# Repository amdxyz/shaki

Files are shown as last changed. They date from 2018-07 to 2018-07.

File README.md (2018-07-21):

# AMDX Shaki

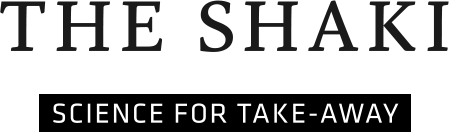
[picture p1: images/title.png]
Shaki title picture


Push - Shake - Love: that's as simple as how the "Shaki" works. If you push a button and shake the stick, a message, a name or a symbol appears in the air. But what the Shaki actually demonstrates is a highly complex phenomenon - the Persistence of vision.

## POV

POV stands for Persistence of vision (https://en.wikipedia.org/wiki/Persistence_of_vision)
The image of an object stays on the retina even after stopping looking at it as the eye and brain actually retain a visual impression for about 1/20 th of a second. It is the principle of movies and animations - and of the small exhibit we at Archimedes Exhibitions created to make this scientific phenomenon playfully comprehensive. You can put the Shaki in your trouser pocket and experience and learn about the Persistence of vision wherever you like, alone or in groups.

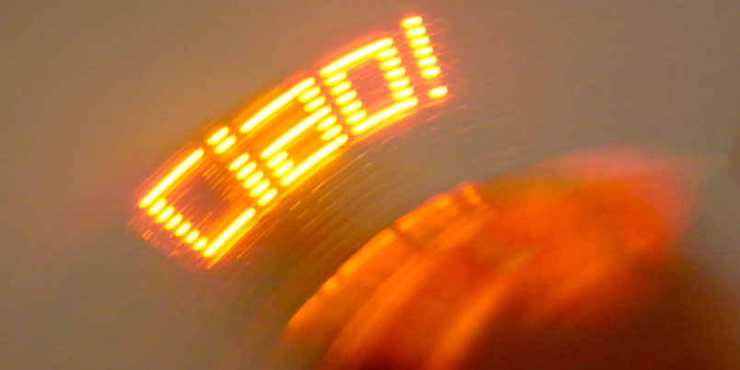
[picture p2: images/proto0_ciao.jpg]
POV Sample picture


## History

The Shaki was developed as part of an internal competition we regularly launch at Archimedes Exhibitions to cultivate creativity and innovative ideas outside the daily working routine. The goal of the competition was to produce a cheap and insightful giveaway for the upcoming ECSITE annual conference (https://www.ecsite.eu/).

The background idea behind our Shaki was kind of a „Gadgetification": taking one of our original size exhibits and shrinking it until it fits into a trouser pocket.

The Shaki is the gadgetified version of our "Spinning Display", a rotating POV display developed for the Science and Technology Centre Ostrava (CZ), as part of the "World of Nature" exhibition (http://stcostrava.cz/setrvacnost-oka).

Archimedes Exhibitions gave away 200 Shakis units among the participants of the 2018 ECSITE conference and, after its big success, decided to release the Shaki's firmware, tools and PCB as open source.

Shaki prototypes

## Components and operation

The Shaki hardware has five main components:

* battery: its power source
* button: connects the battery to the rest of the components
* microcontroller: the brain
* accelerometer: the sensor that detects a shake
* LEDs bar: 8 small light emitting diodes that paint the stored pictures in the air

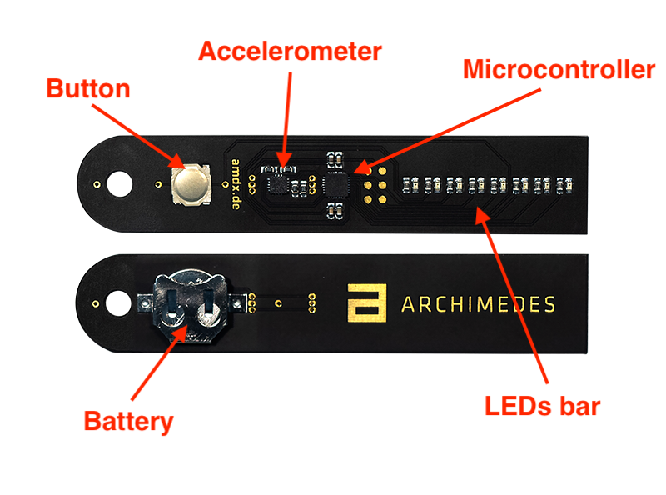
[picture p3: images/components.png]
Components


### Theory of operation

Once the button is pressed and as long as it's being kept pressed, the microcontroller talks to the accelerometer and attempts to detect the motion of the stick in real time. The accelerometer reports its readouts 1.600 times per second.

The idea is to detect the two extremes of a shake motion (a rapid side to side oscillation) and to paint a frame while moving from left to right.

As soon as the microcontroller decides that the stick is moving from left to right, it starts to stream the current frame to the LEDs bar. The frame is composed of several columns and each column is extracted and "transferred" to the LEDs bar using a timer. This transfer means that some LEDs will be lit, some not, according to the "white" or "black" pixels set in the frame.

Each 2.4ms a new column is moved from the microcontroller's memory to the LEDs bar until all the columns have been transferred. From this point on the LEDs shut down and the microcontroller waits until the rightmost point is reached.

Once the rightmost point is reached, the microcontroller decides whether to advance to the next frame or to paint the last one again (depending on the amount of shakes-per-frame defined). The LEDs are kept off until the cycle repeats.

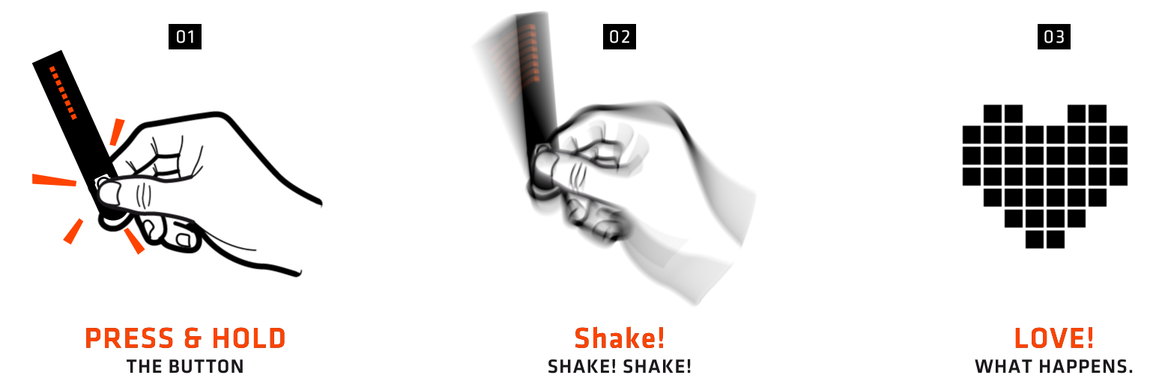
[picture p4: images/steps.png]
Steps


### More details on the components

* Microcontroller: ATMEL ATTiny88 (8kB FLASH, 512B SRAM) clocked at 8Mhz via its internal RC oscillator
* Accelerometer: ST LIS3DH MEMS accelerometer (16bit, I2C/SPI, 5300Hz max update rate)

The accelerometer is connected to the microcontroller via its I2C interface.

## What to find in the repository

This repository is composed of the following:

* eagle: EagleCAD schematics, PCB layout and BOM
* firmware: the software that runs inside the Shakis
* tools: converter and authoring tools to customise the displayed frames

Each folder contains a detailed readme file.

## FAQ

AKA frequently asked questions:

### Can I get an assembled, ready-to-use Shaki?

Yes, write to us: shaki {a} amdx.de

### Can I produce, customise, sell the Shaki?

As long as it fits the terms of the [LICENSE](https://github.com/amdxyz/shaki/blob/master/LICENSE.md), you're more than welcome.

### How can I customise my Shaki?

This repository provides everything you need to do any customisation you may have in mind, but the process requires some technical skills and tools.

In short:

* Produce the frames using a graphic authoring tool or the included of_bitpuncher tool
* Convert the authored graphic (not required when using of_bitpuncher)
* Compile the firmware
* Upload the firmware to the Shaki using a programmer and a programming jig

### Why no USB?

One of the Shaki's primary requirements was to minimize its production costs. It wasn't initially supposed to be released to the public, so we didn't consider a consumer-grade programming interface.

### How can I contribute?

Feel free to file an issue or post a push request!

### Any media?

You can watch a short presentation here: https://www.youtube.com/watch?v=L5a6pu70XJo

And a brief introduction here: http://www.amdx.de/shaki

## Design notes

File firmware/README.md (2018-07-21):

# Shaki firmware

This directory contains the firmware for the Shaki board.

Building the firmware is a required step for customizing the stored frames, since they're backed into the firmware itself (and residing in flash).

The firmware can be built using two IDEs:

* Platformio (http://www.platformio.org)
* Atmel Studio 7 (https://www.microchip.com/mplab/avr-support/atmel-studio-7)

## Frame data

The simplest way to hack the Shaki is to alter the content of its frame buffer.

All the frames shown during a shake, are stored into the header frame_data.h in the variable named "frames".

The file can be generated using one of the two tools provided:

* bitmap_converter
* of_bitpuncher

More information is provided inside the tools folder.

## Modifying the source and/or building it

There are three methods that can be followed to build the firmware:

### Using platformio command line tools

Build the firmware by issuing:

	$ pio run

The firmware can be then uploaded using the target "upload":

	$ pio run -t upload

Check below for notes about uploading.

### Using platformio IDE

Open the project in the IDE and press either build or upload.

### Using Atmel Studio 7

Navigate into atmelstudio and double-click the solution file "atmelstudio.atsln".

The solution can be built pressing F7 (or choosing "Build solution" from the build menu).

In order to upload the firmware or run a debug session, a programming tool must be defined.

## Uploading the firmware

In order to upload the firmware, you need the following tools:

* AVRISP-MKII or compatible
* ISP pogo-pins jig (eg: Sparkfun KIT-11591 https://www.sparkfun.com/products/11591)

The jig should be applied over the exposed programming pads as shown in the following picture:

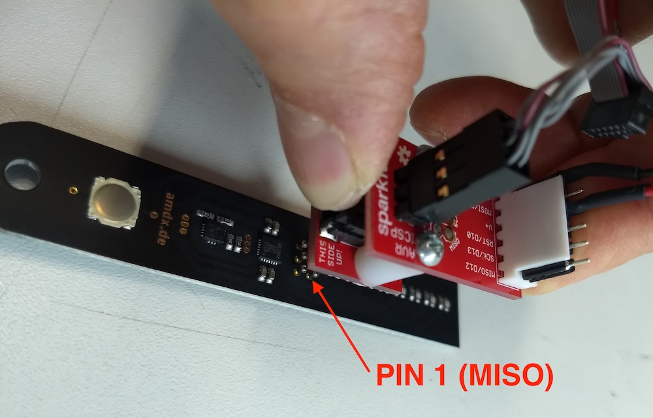
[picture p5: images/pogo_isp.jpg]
Pogo-pins ISP


Once the pogo pins are properly in contact with the pads, the programming can be carried on.

### Using Atmel-ICE

As the AVRISP is no longer in production, it can be replaced with the newer atmel-ICE.

In order to use it with platformio, edit the file boards/shaki.json and modify the key "protocol" under "upload":

	"protocol": "avrispmkii",

to

	"protocol": "atmelice_isp",

Make sure the programmer pigtail is connected to the "AVR" port.

## Fuses

The AMDX Shaki board comes provisioned and pre-programmed with a default pattern. In case you produced the board by yourself, the microcontroller must be provisioned with fuses setting.

The fuses hexes are:

* High: 0xd7
* Low: 0xee

The directory "provisioning" contains two scripts that can be used to set the fuses using avrdude and an AVRISP-MKII programmer. They can be used under windows (.bat) and linux, OSX (.sh), provided that avrdude is available in the PATH.

## Debugging

### Test pattern

A test pattern can be activated by adding a define TEST_PATTERN (see firmware/platfomio.ini).

Once flashed, the firmware will provide two brief blinks to signal the detection of the two motion extremes (left and right).

### Timing test point TP1

TP1 is a timing pin that can be connected to an oscilloscope in order to perform motion analysis.

It offers two debugging modes:

* DEBUG_ON_COLUMN : every time a new column from a frame is transferred to the LED bar, this line asserts shortly
* DEBUG_ON_SHAKE : the line asserts during a left-to-right motion and deasserted otherwise

The two modes can be activated by defining the respective identifiers. Check firmware/platformio.ini file for more information.

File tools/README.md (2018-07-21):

# Tools

This directory contains tools designed to ease the customization of the Shaki's default painted frames.

## Bitmap converter

A python console tool to convert a set of bitmap images into the final target format (a C-Header file), that can be compiled along with the firmware.

## of_bitpuncher

A fully fledged application that allows to design a pattern / sequence.

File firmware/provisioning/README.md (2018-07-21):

# Fuses provisioning

Shaki boards produced by AMDX come always provisioned and require no additional setup.

Self-produced boards require one-time setup for the fuses settings.

## Under windows (Atmel Studio 7)

Make sure the programmer is connected via USB to your PC

* Open the solution file (optional)
* Open the device programming tool (Tools -> Device Programming)
* Select the programmer from the Tool dropdown
* If not selected, choose "ATTiny88" as device
* Press "Apply"
* Make sure that the pogo-pins jig is attached to the board
* Press "Read" to check connection and device signature
* Select "Fuses" on the left navigation column
* Uncheck "LOW.CKDIV8"
* Press "Program"

Ensure that the summary of the action reports all entries with a trailing "OK"

## Under windows (avrdude)

**Note: the drivers installed by Atmel Studio are incompatible with avrdude**

Prerequisite: avrdude must be in the path or the exe and the config file must be moved to this directory

* Make sure that the pogo-pins jig is attached to the board
* Execute the bat file

## Under OSX or Linux

Prerequisite: avrdude must be installed (via homebrew for OSX or any packaging system under linux)

* Make sure that the pogo-pins jig is attached to the board
* Execute the shell script

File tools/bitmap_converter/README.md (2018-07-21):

# Bitmap to Shaki frame data header converter

This tool converts a set of bitmap files to the C-header format required by the firmware to store the frames data.

## Requirements

### Converter

The converter requires python 2.7 or python 3 and uses PIL/Pillow for image operations. This requirement can be fulfilled in different ways depending on the working platform.

A typical workflow using virtualenv:

	$ virtualenv _venv
	$ source _venv/bin/activate
	$ pip install -Ur requirements.txt

Remember to activate the virtualenv before using the converter.

### Input files

The converter expects the input files to meet the following requirements:

* Color mode: bitmap (1 bit per pixel)
* White pixels turn the LEDs on
* The height must be exactly 8 pixels
* The width is arbitrary, but widths below 12 work best
* Any common image compression is supported, PNG is suggested
* The number of frames is arbitrary (see below for the memory limits)

Check the files provided in the samples folder.

## Usage

The simplest usage example:

	$ ./convert.py samples/amdx/*

The invocation above uses two sample bitmaps provided in the amdx samples folder and converts them into a file "frame_data.h" in the current working directory.

A more complete example:

	$ ./convert.py --spf 2 --output ../../firmware/src/frame_data.h samples/helloworld/*

* --spf 2: indicates that each frame should be painted for two shakes
* --output ../../firmware/src/frame_data.h: overwrite the current frame_data.h file
* Files list: this is the ordered list of bitmap frames to convert. Globbing is supported.

### Note about spf

The "spf" parameter (standing for shakes-per-frame) defines how the frames are coupled to the POV scan (or shake).

A value greater than zero (the default of the tool is 5) will repeat the paint of a single frame for more than once.

Repeating helps the user to properly understand the painted frame.

An SPF of 1 may be used with frames sequences that are supposed to show a fluid animation and where the sequence in its whole is more representative than each single frame.

## Memory limits

Each row requires one byte of flash memory. The memory available for the frame buffer is around 7200 bytes, which means 7200 columns maximum in total.

When using 8x8 frames, for example, the maximum number of frames that can be stored is roughly 112.

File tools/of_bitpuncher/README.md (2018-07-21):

# of_bitpuncher

This application helps to create patterns and sequences through a graphical interface. It allows you to upload new patterns to your Shaki by using platformIO or to export them to a C-header file suitable for the Shaki firmware.

**Note: Tested on OSX with openframeworks 0.10.0**

## Requirements

### openframeworks

The of_bitpuncher app is based on openframeworks, an open source C++ toolkit. Download it from https://openframeworks.cc/.

The app uses the addon ofxGuiExtended by frauzufall. Clone it to the openframeworks addons directory.

    $ cd ../of_vX.XX.X_osx_release/addons
    $ git clone https://github.com/frauzufall/ofxGuiExtended.git

Create a new openframeworks project on top of the of_bitpuncher source files. Navigate to the project generator app coming along with openframeworks.

    $ open ../of_vX.XX.X_osx_release/projectGenerator/projectGenerator.app

Under the tab 'create/update' fill in the following:

    Project name: 'of_bitpuncher'
    Project path: '../tools/'
    Addons: 'ofxGuiExtended'

Click on 'Generate'. This will automatically create the make file needed to compile the software on your computer.

To compile:

    $ cd ../tools/of_bitpuncher
    $ make

To run the app:

    $ make run
Alternatively execute ../tools/of_bitpuncher/bin/of_bitpuncher.app

### platformIO

PlatformIO is required to compile and upload the produced patterns / sequences to the Shaki with a one-button operation. Alternatively, the patterns / sequences can be exported to a C-header frame data file suitable for the current firmware.

## Usage

### Edit a frame

Create a pattern by clicking / dragging the mouse over the 8x8 matrix on the top. It is also possible to use the key input to have a quick access to predefined letters and numbers. Only letters from 'a' to 'z' and numbers from '0' to '9' are implemented.

### Create a sequence

In order to create words, animation or multiple icons create a sequence by adding more frames. Click on '+' to add one frame or click on the trash can icon to delete the currently selected frame.

### Shakes per frame

'Shakes per frame' defines the number of shakes before the Shaki advances to the next frame.

### Templates

Pick one of the templates on the right-hand side for quick and easy start. There is also the option to add the current sequence to the template list by clicking on 'Add template' at the bottom right.

### Reset / Upload / Export

Click on 'Reset' to start from scratch. 'Upload' will flash the firmware on the Shaki (platformIO required). 'Export' allows you to save the frame_data.h file on you computer.

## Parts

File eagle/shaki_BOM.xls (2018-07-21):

Part Name | Quantity | Type | Package | Value | Company | Part Number
R1-R4 | 4 | Resistor | 0603 | 10k
R10-R17 | 8 | Resistor | 0603 | 100R/1%
C1,C3 | 2 | Capacitor | 0603 | 100nF
C2 | 1 | Capacitor | 0603 | 1µF/16V
C4 | 1 | Capacitor | 0603 | 10µF/16V
D1-D8 | 8 | LED Orange | 0603 |  | Lite-On-Inc. | LTST-C194KFKT
U1 | 1 | Microcontroller | QFN28 |  | Microchip | ATTINY88-MMU
U2 | 1 | 3 Axis Sensor | LGA16 3x3 |  | ST | LIS3DHTR
Bat1 | 1 | 1220 Battery Holder | 1220 SMD | 3V | Keystone | 3000
SW1 | 1 | SMD Button |  |  | Alps | SKRRABE010

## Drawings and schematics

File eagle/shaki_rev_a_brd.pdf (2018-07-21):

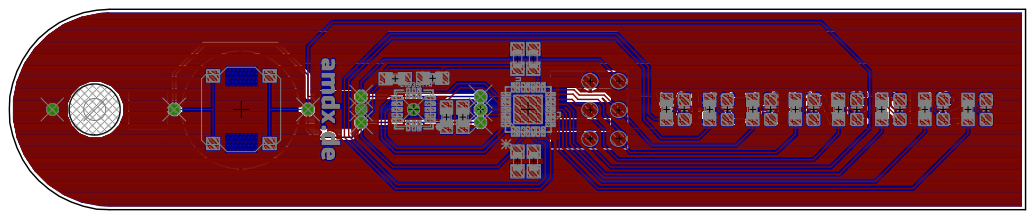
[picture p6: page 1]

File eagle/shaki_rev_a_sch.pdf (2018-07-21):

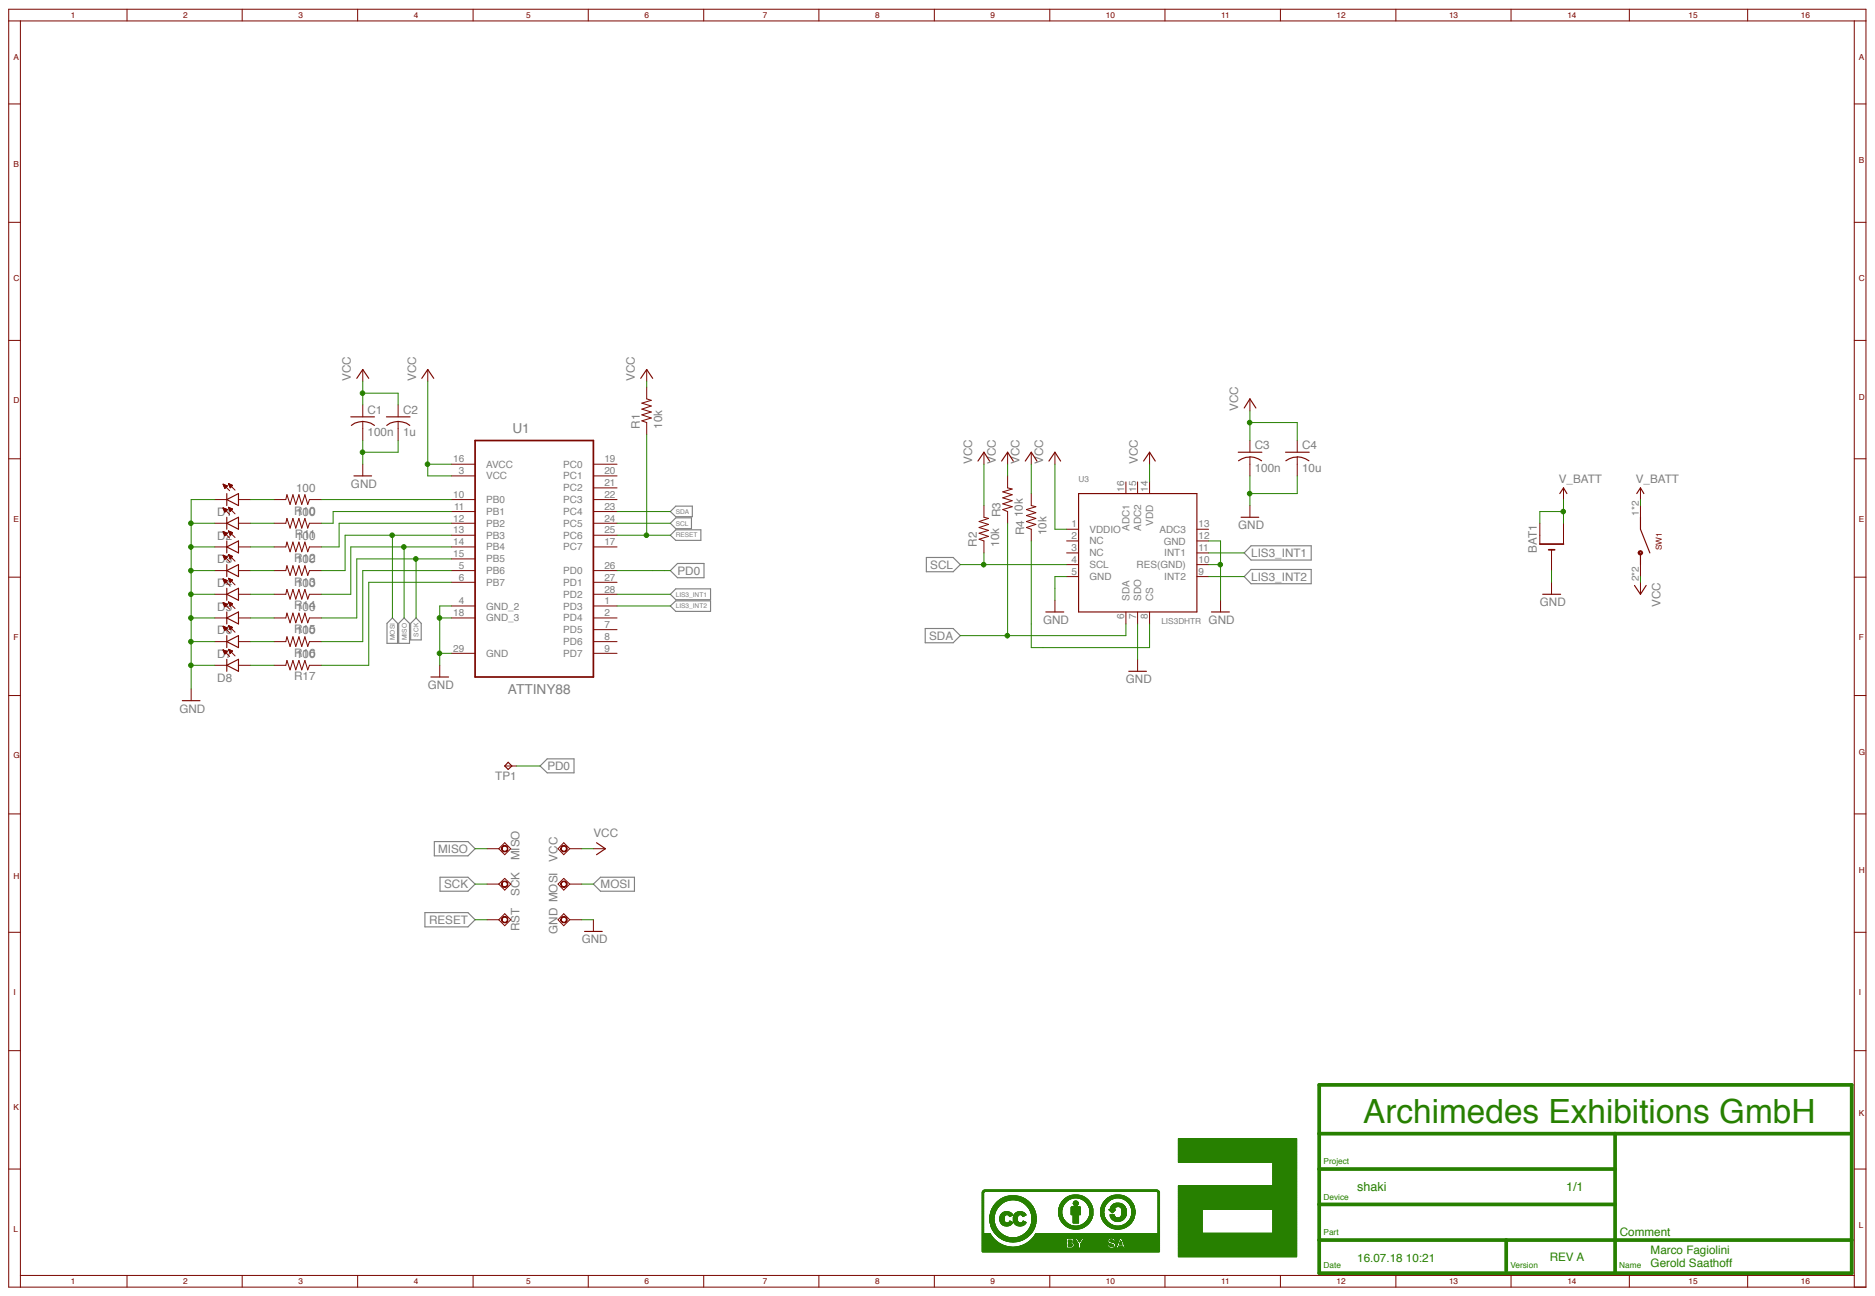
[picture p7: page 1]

16.07.18 10:21 Date | REV A Version | Marco Fagiolini Gerold Saathoff Name

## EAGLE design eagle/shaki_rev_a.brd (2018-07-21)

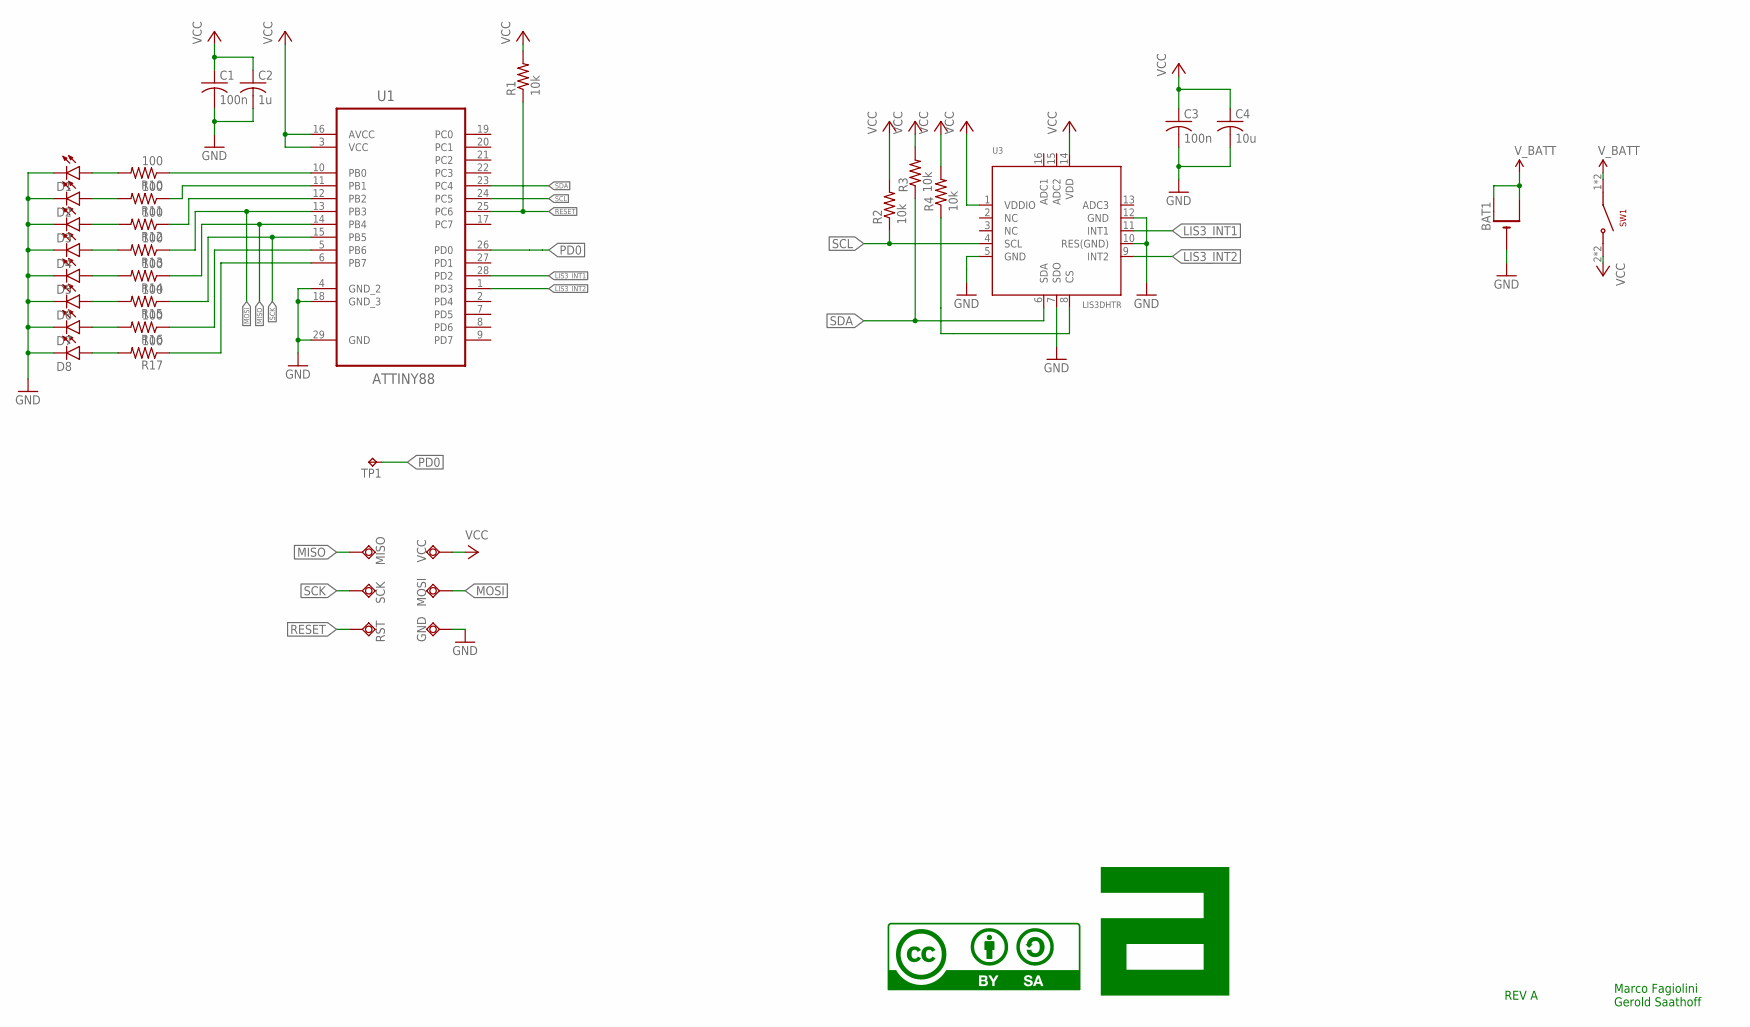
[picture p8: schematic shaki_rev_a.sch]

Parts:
BAT1: CR1220SMT; CR1220-SMD
C1, C3: 100n; C0603K
C2: 1u; C0603K
C4: 10u; C0603K
D1, D2, D3, D4, D5, D6, D7, D8: LED0603; LED-0603
GND: TPSQTP13R; TP13R
MISO: TPSQTP13R; TP13R
MOSI: TPSQTP13R; TP13R
R1, R2, R3, R4: 10k; 0603
R10, R11, R12, R13, R14, R15, R16, R17: 100; 0603
RST: TPSQTP13R; TP13R
SCK: TPSQTP13R; TP13R
SW1: SKRRABE010
TP1: TESTPAD
U1: ATTINY88; QFN45P400X400X100-29N
U3: LIS3DHTR; LGA16_3X3MM
VCC: TPSQTP13R; TP13R

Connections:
GND: BAT1.-, C1.2, C2.2, C3.2, C4.2, D1.C, D2.C, D3.C, D4.C, D5.C, D6.C, D7.C, D8.C, GND.TP, U1.4 (GND_2), U1.18 (GND_3), U1.29 (GND), U3.5 (GND), U3.7 (SDO), U3.10 (RES(GND)), U3.12 (GND)
LED1: R10.1, U1.10 (PB0)
LED2: R11.1, U1.11 (PB1)
LED3: R12.1, U1.12 (PB2)
LED7: R16.1, U1.5 (PB6)
LED8: R17.1, U1.6 (PB7)
LIS3_INT1: U1.28 (PD2), U3.11 (INT1)
LIS3_INT2: U1.1 (PD3), U3.9 (INT2)
MISO: MISO.TP, R14.1, U1.14 (PB4)
MOSI: MOSI.TP, R13.1, U1.13 (PB3)
unnamed: R4.1, U3.8 (CS)
unnamed: D1.A, R10.2
unnamed: D2.A, R11.2
unnamed: D3.A, R12.2
unnamed: D4.A, R13.2
unnamed: D5.A, R14.2
unnamed: D6.A, R15.2
unnamed: D7.A, R16.2
unnamed: D8.A, R17.2
PD0: TP1.P$1, U1.26 (PD0)
RESET: R1.1, RST.TP, U1.25 (PC6)
SCK: R15.1, SCK.TP, U1.15 (PB5)
SCL: R2.1, U1.24 (PC5), U3.4 (SCL)
SDA: R3.1, U1.23 (PC4), U3.6 (SDA)
VCC: C1.1, C2.1, C3.1, C4.1, R1.2, R2.2, R3.2, R4.2, SW1.2, SW1.4 (2), U1.3 (VCC), U1.16 (AVCC), U3.1 (VDDIO), U3.14 (VDD), VCC.TP
V_BATT: BAT1.+$1 (+), BAT1.+$2 (+1), SW1.1, SW1.3 (1)

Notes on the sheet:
REV A
Marco Fagiolini Gerold Saathoff

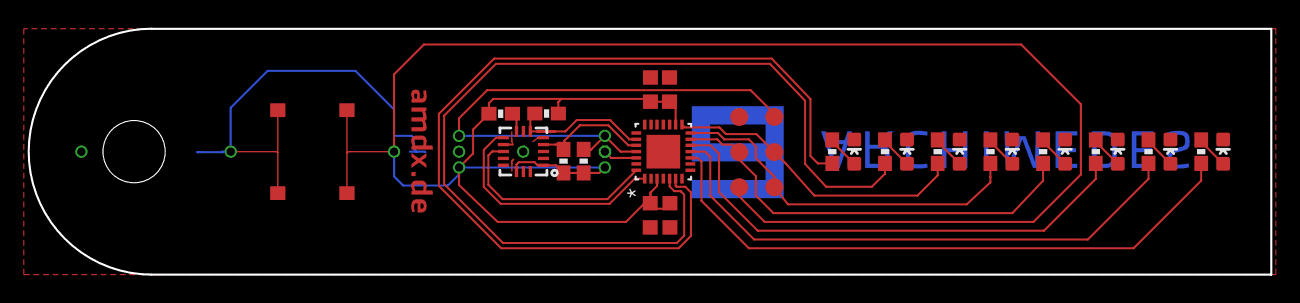
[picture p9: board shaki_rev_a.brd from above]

Board: 2 copper layers, 89.8 x 17.8 mm, 35 parts (1 on the bottom side), 26 nets.

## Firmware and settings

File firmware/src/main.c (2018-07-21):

/* ***********************************************************************
    Shaki firmware
    Copyright (C) 2016-2018 Marco Fagiolini <mfx@amdx.de>

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
    You should have received a copy of the GNU General Public License
    along with this program.  If not, see <https://www.gnu.org/licenses/>.
* ***********************************************************************/

#include <avr/io.h>
#include <util/delay.h>
#include <avr/sleep.h>
#include <avr/interrupt.h>
#include <avr/pgmspace.h>

#include "lis3dh.h"
#include "frame_data.h"


// Direction inversion threshold
#define THRESHOLD_ABS_ACCEL     60
// Column timer sync
// 8ms rollover at 16bit = 122ns step. 20000 is about 2.44ms
#define TIMER_PERIOD            20000

#define DEBUG_PIN               PIND0
#define DEBUG_DDR               DDRD
#define SET_DEBUG_PIN()         PORTD |= DEBUG_PIN
#define UNSET_DEBUG_PIN()       PORTD &= ~DEBUG_PIN


typedef enum Error {
    ERROR_NONE = 0,
    ERROR_ACCELEROMETER = 1
} Error;

typedef enum Direction {
    DIR_UNKNOWN,
    DIR_LEFT_TO_RIGHT,
    DIR_RIGHT_TO_LEFT
} Direction;

Direction direction = DIR_UNKNOWN;

// Index of the column within the frame being painted
volatile uint8_t col_index = 0;
// A flag set by the ISR upon the accelerometer's interrupt trigger
volatile uint8_t rdy_flag = 1;
// Index of the current frame being painted
uint8_t frame_index = 0;


// FORWARD PROTOTYPES

void paint_column();


// INTERRUPT SERVICE ROUTINES

ISR(TIMER1_COMPA_vect)
{
#ifdef TEST_PATTERN
    // Clear the LEDs (the test pattern sets a solid column at the motion's extremes)
    PORTB = 0;
#else
    // Use the frames buffer to set the LEDs pattern
    paint_column();
#endif
}

ISR(INT0_vect)
{
    // Mark the availability of new accelerometer data
    rdy_flag = 1;
}


void paint_column()
{
#ifdef DEBUG_ON_COLUMN
    SET_DEBUG_PIN();
#endif

    if (col_index < COLS && direction == DIR_LEFT_TO_RIGHT) {
        // Fetch a column from the frames stack and copy it to the PORTB register
        // The post-increment forwards the column index
        PORTB = pgm_read_byte(&(frames[frame_index][col_index++]));
    } else {
        // When moving from right to left keep the led bar off
        PORTB = 0;
    }

#ifdef DEBUG_ON_COLUMN
    UNSET_DEBUG_PIN();
#endif

    // Reset the timer
    TCNT1 = 0;
}

void report_error(Error error)
{
    // Endless loop reporting errors using the LEDs bar
    while (1) {
        PORTB = (uint8_t)error;
        _delay_ms(200);
        PORTB = 0;
        _delay_ms(200);
    }
}

void init()
{
    // Configure timer1 no prescaler, CTC (max ~8ms rollover)
    // this timer is used to clock in the columns
    // Notice that he scan rate is not adaptive
    TCCR1A = 0;
    TCCR1B = (1 << WGM12) | (1 << CS10);
    OCR1A = TIMER_PERIOD;

    // Enable INT0 on rising edge (connected to LIS3 INT1)
    EICRA = (1 << ISC00) | (1 << ISC01);
    EIMSK = (1 << INT0);

    // All outputs on port B
    DDRB = 0xff;

#if defined(DEBUG_ON_SHAKE) || defined(DEBUG_ON_COLUMN)
    // Enable output on debug pin
    DEBUG_DDR |= DEBUG_PIN;
#endif

    // Initialize the accelerometer and report error in case of failure
    if (lis3dh_init() != 0) {
        report_error(ERROR_ACCELEROMETER);
    }

    // Enable timer1 interrupts
    TIMSK1 = (1 << OCIE1A);

    sei();
}

void eval_motion(AccelVec *accel_vec)
{
    static int8_t extreme_val = 0;

#if SPF > 1
    static uint8_t frame_decimator = 0;
#endif

    if (accel_vec->y > THRESHOLD_ABS_ACCEL && direction != DIR_LEFT_TO_RIGHT) {
        if (accel_vec->y > extreme_val) {
            // Find the maximum
            extreme_val = accel_vec->y;
        } else {
            // Maximum found (the acceleration module gradient is now negative)
            // The leftmost position of the shake is reached
#ifdef DEBUG_ON_SHAKE
            SET_DEBUG_PIN();
#endif
            // Reset column index to the first one
            // The enqueued frame is primed and ready to paint from its first column
            direction = DIR_LEFT_TO_RIGHT;
            col_index = 0;

#ifdef TEST_PATTERN
            // Paint a single, filled column at the leftmost extreme of the motion
            // This will be then cleared at next timer1 overflow
            TCNT1 = 0;
            PORTB = 0xff;
#else
            paint_column();
#endif
        }
    } else if (accel_vec->y < -THRESHOLD_ABS_ACCEL && direction != DIR_RIGHT_TO_LEFT) {
        if (accel_vec->y < extreme_val) {
            // Find the minimum
            extreme_val = accel_vec->y;
        } else {
            // Minimum found (the acceleration module gradient is now positive)
            // The rightmost position of the shake is reached
#ifdef DEBUG_ON_SHAKE
            UNSET_DEBUG_PIN();
#endif

#ifdef TEST_PATTERN
            // Paint a single, filled column at the rightmost extreme of the motion
            // This will be then cleared at next timer1 overflow
            TCNT1 = 0;
            PORTB = 0xff;
#endif
            // Update the direction
            direction = DIR_RIGHT_TO_LEFT;

#if SPF > 1
            // If the decimator is used, do not advance the frame count until
            // SPF frames are persisted
            ++frame_decimator;
            if (frame_decimator == SPF) {
                frame_index = (frame_index + 1) % FRAMES_COUNT;
                frame_decimator = 0;
            }
#else
            // When not using the decimator, advance the frame at each shake
            frame_index = (frame_index + 1) % FRAMES_COUNT;
#endif
        }
    }
}


int main(void)
{
    AccelVec accel_vec;

    init();

    while(1) {
        // Wait until the accelerometer asserts its INT1 line
        while (rdy_flag == 0);

        // Pull acceleration data from the accelerometer's registers
        lis3dh_update(&accel_vec);

        // Process the acceleration vector
        eval_motion(&accel_vec);
    }
}

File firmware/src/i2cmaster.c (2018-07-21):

/*************************************************************************
* Title:    I2C master library using hardware TWI interface
* Author:   Peter Fleury <pfleury@gmx.ch>  http://jump.to/fleury
* File:     $Id: twimaster.c,v 1.4 2015/01/17 12:16:05 peter Exp $
* Software: AVR-GCC 3.4.3 / avr-libc 1.2.3
* Target:   any AVR device with hardware TWI
* Usage:    API compatible with I2C Software Library i2cmaster.h
**************************************************************************/
#include <inttypes.h>
#include <util/twi.h>

#include "i2cmaster.h"


/* define CPU frequency in hz here if not defined in Makefile */
#ifndef F_CPU
#define F_CPU 4000000UL
#endif

/* I2C clock in Hz */
#define SCL_CLOCK  400000L


/*************************************************************************
 Initialization of the I2C bus interface. Need to be called only once
*************************************************************************/
void i2c_init(void)
{
  /* initialize TWI clock: 100 kHz clock, TWPS = 0 => prescaler = 1 */

  TWSR = 0;                         /* no prescaler */
  TWBR = ((F_CPU/SCL_CLOCK)-16)/2;  /* must be > 10 for stable operation */

}/* i2c_init */


/*************************************************************************
  Issues a start condition and sends address and transfer direction.
  return 0 = device accessible, 1= failed to access device
*************************************************************************/
unsigned char i2c_start(unsigned char address)
{
    uint8_t   twst;

    // send START condition
    TWCR = (1<<TWINT) | (1<<TWSTA) | (1<<TWEN);

    // wait until transmission completed
    while(!(TWCR & (1<<TWINT)));

    // check value of TWI Status Register. Mask prescaler bits.
    twst = TW_STATUS & 0xF8;
    if ( (twst != TW_START) && (twst != TW_REP_START)) return 1;

    // send device address
    TWDR = address;
    TWCR = (1<<TWINT) | (1<<TWEN);

    // wail until transmission completed and ACK/NACK has been received
    while(!(TWCR & (1<<TWINT)));

    // check value of TWI Status Register. Mask prescaler bits.
    twst = TW_STATUS & 0xF8;
    if ( (twst != TW_MT_SLA_ACK) && (twst != TW_MR_SLA_ACK) ) return 1;

    return 0;

}/* i2c_start */


/*************************************************************************
 Issues a start condition and sends address and transfer direction.
 If device is busy, use ack polling to wait until device is ready

 Input:   address and transfer direction of I2C device
*************************************************************************/
void i2c_start_wait(unsigned char address)
{
    uint8_t   twst;

    while ( 1 )
    {
        // send START condition
        TWCR = (1<<TWINT) | (1<<TWSTA) | (1<<TWEN);

        // wait until transmission completed
        while(!(TWCR & (1<<TWINT)));

        // check value of TWI Status Register. Mask prescaler bits.
        twst = TW_STATUS & 0xF8;
        if ( (twst != TW_START) && (twst != TW_REP_START)) continue;

        // send device address
        TWDR = address;
        TWCR = (1<<TWINT) | (1<<TWEN);

        // wail until transmission completed
        while(!(TWCR & (1<<TWINT)));

        // check value of TWI Status Register. Mask prescaler bits.
        twst = TW_STATUS & 0xF8;
        if ( (twst == TW_MT_SLA_NACK )||(twst ==TW_MR_DATA_NACK) )
        {
            /* device busy, send stop condition to terminate write operation */
            TWCR = (1<<TWINT) | (1<<TWEN) | (1<<TWSTO);

            // wait until stop condition is executed and bus released
            while(TWCR & (1<<TWSTO));

            continue;
        }
        //if( twst != TW_MT_SLA_ACK) return 1;
        break;
     }
}/* i2c_start_wait */


/*************************************************************************
 Issues a repeated start condition and sends address and transfer direction

 Input:   address and transfer direction of I2C device

 Return:  0 device accessible
          1 failed to access device
*************************************************************************/
unsigned char i2c_rep_start(unsigned char address)
{
    return i2c_start( address );

}/* i2c_rep_start */


/*************************************************************************
 Terminates the data transfer and releases the I2C bus
*************************************************************************/
void i2c_stop(void)
{
    /* send stop condition */
    TWCR = (1<<TWINT) | (1<<TWEN) | (1<<TWSTO);

    // wait until stop condition is executed and bus released
    while(TWCR & (1<<TWSTO));

}/* i2c_stop */


/*************************************************************************
  Send one byte to I2C device

  Input:    byte to be transfered
  Return:   0 write successful
            1 write failed
*************************************************************************/
unsigned char i2c_write( unsigned char data )
{
    uint8_t   twst;

    // send data to the previously addressed device
    TWDR = data;
    TWCR = (1<<TWINT) | (1<<TWEN);

    // wait until transmission completed
    while(!(TWCR & (1<<TWINT)));

    // check value of TWI Status Register. Mask prescaler bits
    twst = TW_STATUS & 0xF8;
    if( twst != TW_MT_DATA_ACK) return 1;
    return 0;

}/* i2c_write */


/*************************************************************************
 Read one byte from the I2C device, request more data from device

 Return:  byte read from I2C device
*************************************************************************/
unsigned char i2c_readAck(void)
{
    TWCR = (1<<TWINT) | (1<<TWEN) | (1<<TWEA);
    while(!(TWCR & (1<<TWINT)));

    return TWDR;

}/* i2c_readAck */


/*************************************************************************
 Read one byte from the I2C device, read is followed by a stop condition

 Return:  byte read from I2C device
*************************************************************************/
unsigned char i2c_readNak(void)
{
    TWCR = (1<<TWINT) | (1<<TWEN);
    while(!(TWCR & (1<<TWINT)));

    return TWDR;

}/* i2c_readNak */

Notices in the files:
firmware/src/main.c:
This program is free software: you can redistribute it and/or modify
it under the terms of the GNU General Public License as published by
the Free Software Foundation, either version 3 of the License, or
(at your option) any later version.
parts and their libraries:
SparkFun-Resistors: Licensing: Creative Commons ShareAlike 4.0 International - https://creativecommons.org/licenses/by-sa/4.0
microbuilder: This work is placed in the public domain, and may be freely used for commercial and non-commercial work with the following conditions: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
